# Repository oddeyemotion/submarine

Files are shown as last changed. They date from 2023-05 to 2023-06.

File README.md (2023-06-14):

# Brief introduction

"Submarine" is a hybrid 4WD, Bluetooth-controlled competitive robot car. It is capable of collecting and holding solid game pieces of varying profile while moving across the playing field with desired accuracy and excessively high speed.

Our robot was constructed in a 7-week period regarding M.E.R.C 2023 tournament. In the end we were eliminated from the competition in the quarterfinals, but we gained a lot of new experiences, insights, and connections, and this was honestly an invaluable experience.

Team Submarine: An Thien Dinh (Samuel/Sam), Tan Ngoc Doan, Bao Quang Vo, Huy Quang Nguyen, Hang Thi-Thuy Le (Arris, Team captain).

Official documentation (English): https://oddeyemotion.github.io/odd/projects/p04-submarine

Project logs (Vietnamese): https://projectcocoon.org/projects/209/submarine#tab=logs

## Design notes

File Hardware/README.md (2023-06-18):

# Hardware

In this folder you may find useful resources about our robot's hardware.

## DIY 12-roller omni wheel
STL files for 3D printing can be located in ***DIY 12-roller omni wheel*** folder, or you can also visit [Thingiverse](https://www.thingiverse.com/thing:6040100).

More details about the development of this design at
[Drivetrain - @oddeyemotion's Project Documentation](https://oddeyemotion.github.io/odd/projects/p04-submarine/p04-30-39-technical-details/p04-32-hardware/p04-32-00-drivetrain/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)

This wheel design is part of a robot car project I made with some friends for a school competition, perfectly compatible with common 12mm hex wheel adapter.

I used the original design as a guide to redraw it with the same diameter as my tractor wheels, which are approximately 66-67mm in diameter. I replaced the paper clips, which are about 1mm in diameter, with a bunch of 2mm steel rods that were cut to 25-27mm in length.

Our printer has an error margin of about 0.4mm.

It is recommended to use 3 layers of heat shrink tubing for each roller's coverage.

Order of assembly: Top half 1 - Top half 2 - Middle plus - Middle - Bottom half 2 - Bottom half 1

Secured with:

6x regular 8mm M3 bolts layered with 3x female M3 brass hex standoff pillar rod spacer in the middle
12x regular pairs of 12mm M2 bolts and nuts (recommended 10mm in length for better fit)

## Gripper (final version)
Source files will be updated in the future.

More details about the development of this design at [End effector - @oddeyemotion's Project Documentation](https://oddeyemotion.github.io/odd/projects/p04-submarine/p04-30-39-technical-details/p04-32-hardware/p04-32-02-ee/)

## Gear power transmission system
More details at [Manipulator - @oddeyemotion's Project Documentation](https://oddeyemotion.github.io/odd/projects/p04-submarine/p04-30-39-technical-details/p04-32-hardware/p04-32-01-manipulator/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)

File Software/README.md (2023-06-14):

# Software

In this folder you may find useful resources about our robot's software.

### Chassis-mounted Arduino program
aaaaa

### Gripper-mounted Arduino program
bbbbb

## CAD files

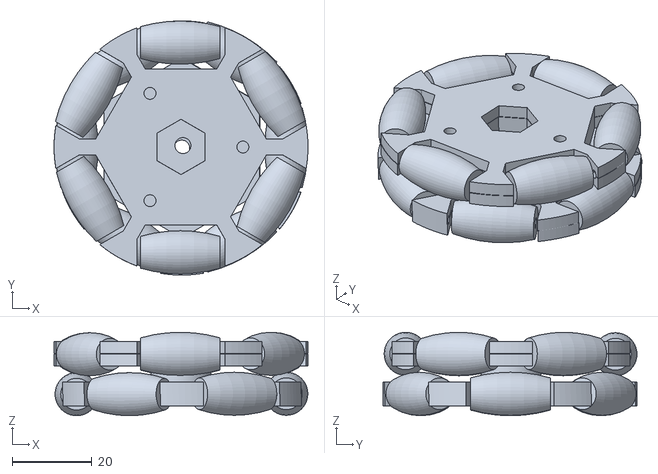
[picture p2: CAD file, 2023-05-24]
3D files/omni wheel 3d.stl
63.6 x 63.6 x 20.9

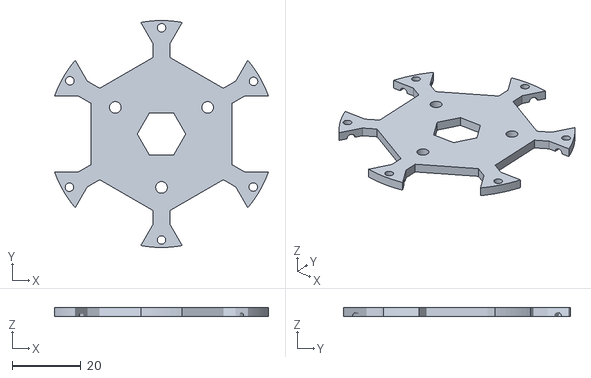
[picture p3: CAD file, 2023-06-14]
Hardware/diy-12-roller-omni-wheel/top half 2 2mm5.stl
62.2 x 66.0 x 2.50

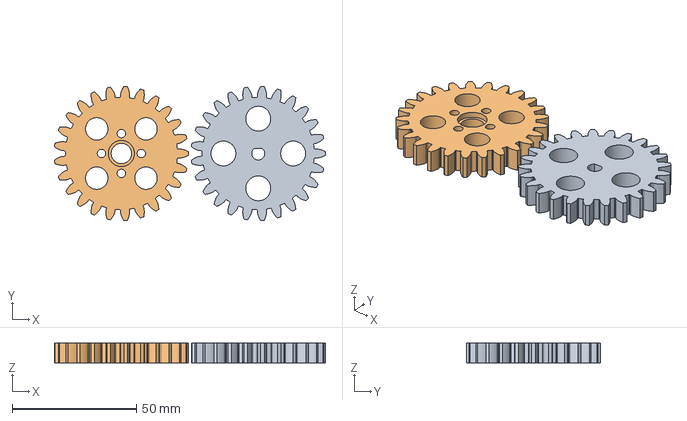
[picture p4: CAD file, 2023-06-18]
Hardware/gear-power-transmission-system/stepper-motor-power-transmission-system.step
108.9 x 54.0 x 8.00 mm
Spur Gear (13 teeth)
Spur Gear (25 teeth)

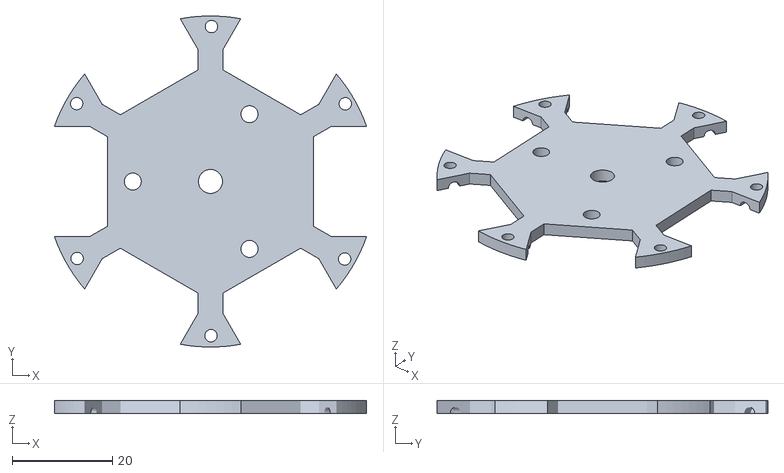
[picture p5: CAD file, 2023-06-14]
Hardware/diy-12-roller-omni-wheel/bottom half 2 2mm5.stl
62.2 x 66.0 x 2.50

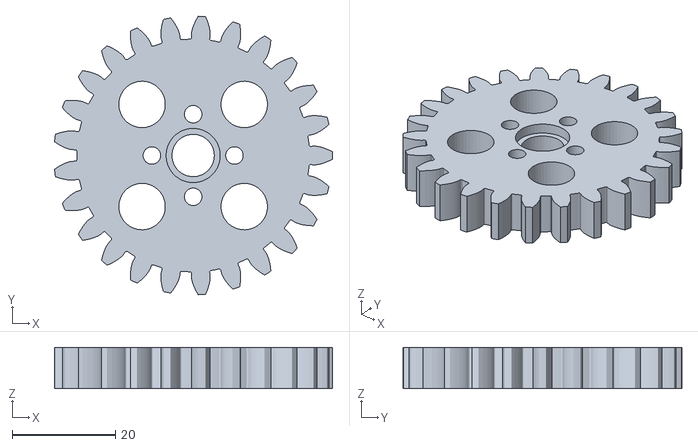
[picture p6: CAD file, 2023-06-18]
Hardware/gear-power-transmission-system/spur-gear-25-teeth-1-1-transmission.stl
53.9 x 54.0 x 8.00

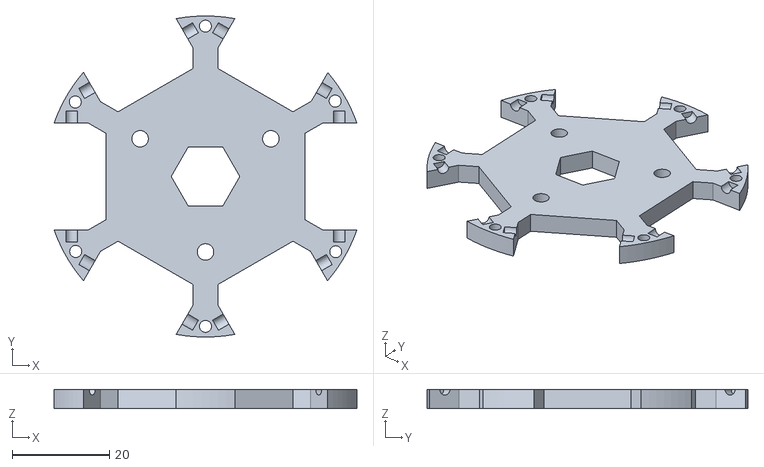
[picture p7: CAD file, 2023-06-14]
Hardware/diy-12-roller-omni-wheel/top half 1 4mm.stl
62.2 x 66.0 x 4.00

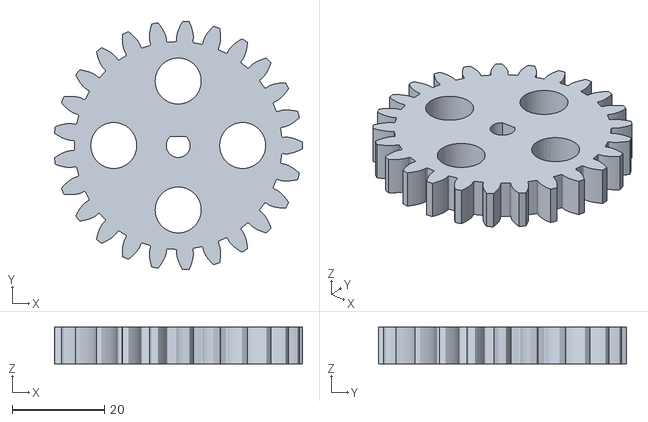
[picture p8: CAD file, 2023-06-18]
Hardware/gear-power-transmission-system/spur-gear-25-teeth-nema-42-stepper.stl
53.9 x 54.0 x 8.00

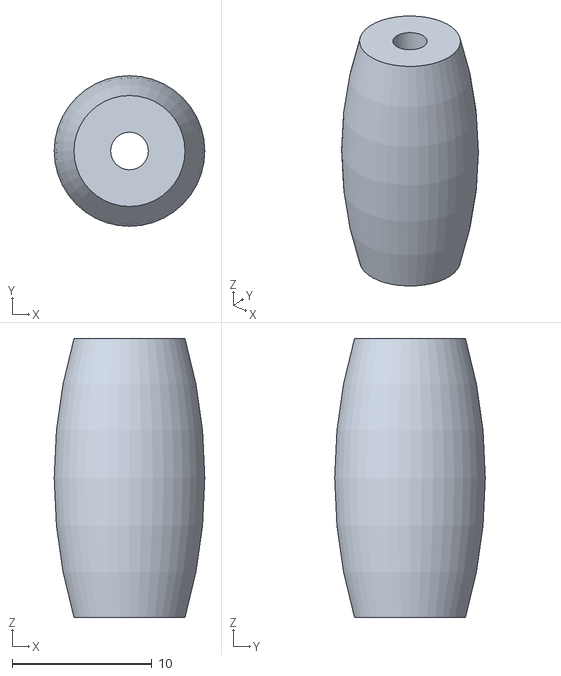
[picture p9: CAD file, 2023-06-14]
Hardware/diy-12-roller-omni-wheel/Omni_Grip_Roller.stl
10.8 x 10.8 x 20.0

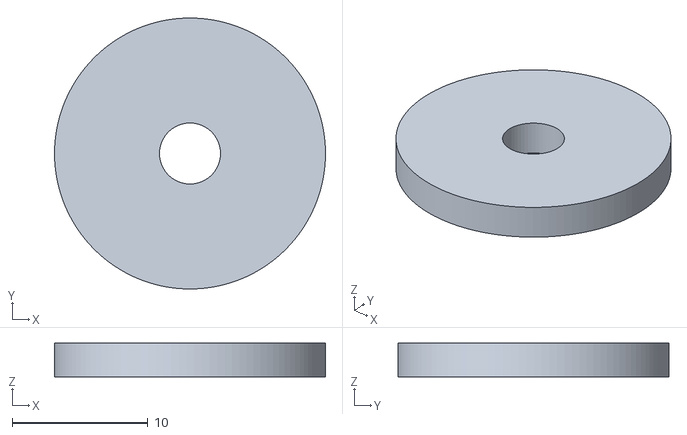
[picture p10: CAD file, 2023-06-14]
Hardware/diy-12-roller-omni-wheel/middle 2mm5.stl
20.0 x 20.0 x 2.50

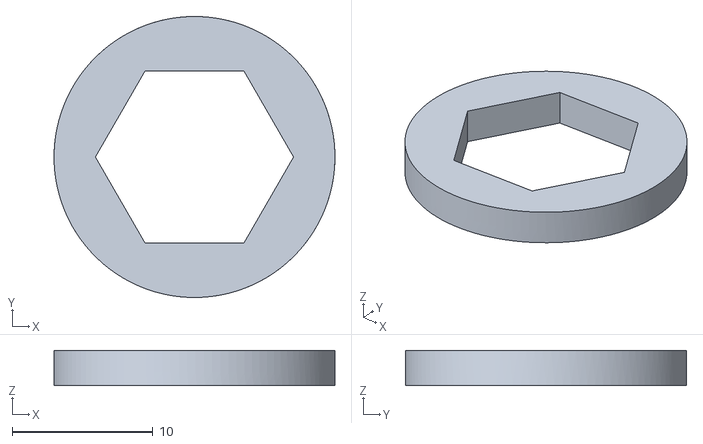
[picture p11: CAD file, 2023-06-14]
Hardware/diy-12-roller-omni-wheel/middle plus 2mm5.stl
20.0 x 20.0 x 2.50

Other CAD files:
Hardware/diy-12-roller-omni-wheel/bottom half 1 4mm.stl
Hardware/gear-power-transmission-system/stepper-motor-power-transmission-system.f3d

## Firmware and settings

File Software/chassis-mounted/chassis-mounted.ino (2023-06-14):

#include <SoftwareSerial.h>
#include <util/atomic.h>
#include <Wire.h>

//Mega
/*
 only the following can be used for RX: 10, 11, 12, 13, 14, 15, 50, 51, 52, 53, A8 (62), A9 (63), A10 (64), A11 (65), A12 (66), A13 (67), A14 (68), A15 (69)
 */
const int MPU = 0x68; // MPU6050 I2C address
float GyroX;
float gyroAngleX; //used in void loop()
float AccErrorX, GyroErrorX;
float elapsedTime, currentTime, previousTime;
int c = 0;
int temp = 0;
int  SpeedTurn = 190;
float previousAngleX = 0;

#define dirPin 6
#define stepPin 7

#define ENLF  2 // LF = Left Front = motor số 2, mạch cầu A
#define ENRF  3 // RF = Right Front = motor số 1, mạch cầu A
#define ENLB  4 // LB = Left Back = motor số 4, mạch cầu B
#define ENRB  5 // RB = Right Back = motor số 3, mạch cầu B
    
#define LF1  22 //IN3A, LF = Left Front = motor số 2, mạch cầu A
#define LF2  23 //IN4A, LF = Left Front = motor số 2, mạch cầu A
#define RF1  24 //IN1A, RF = Right Front = motor số 1, mạch cầu A
#define RF2  25 //IN2A, RF = Right Front = motor số 1, mạch cầu A
    
#define LB1  26 //IN3B, LB = Left Back = motor số 4, mạch cầu B
#define LB2  27 //IN4B, LB = Left Back = motor số 4, mạch cầu B
#define RB1  28 //IN1B, RB = Right Back = motor số 3, mạch cầu B
#define RB2  29 //IN2B, RB = Right Back = motor số 3, mạch cầu B
int command;
int Speed=130;
int LSpeed = Speed;
int RSpeed = Speed;
SoftwareSerial mySerial(50,51); //(TX,RX)

void setup() {
  Serial.begin(9600);
  Wire.begin();                      // Initialize comunication
  Wire.beginTransmission(MPU);       // Start communication with MPU6050 // MPU=0x68
  Wire.write(0x6B);                  // Talk to the register 6B
  Wire.write(0x00);                  // Make reset - place a 0 into the 6B register
  Wire.endTransmission(true);        //end the transmission
  // Call this function if you need to get the IMU error values for your module
  calculateError();
  delay(20);
  pinMode(LF1,OUTPUT);
  pinMode(LF2,OUTPUT);
  pinMode(RF1,OUTPUT);
  pinMode(RF2,OUTPUT);
  
  pinMode(ENLF,OUTPUT);
  pinMode(ENRF,OUTPUT);
  
  pinMode(LB1,OUTPUT);
  pinMode(LB2,OUTPUT);
  pinMode(RB1,OUTPUT);
  pinMode(RB2,OUTPUT);

  pinMode(ENLB,OUTPUT);
  pinMode(ENRB,OUTPUT);

  pinMode(stepPin, OUTPUT);
  pinMode(dirPin, OUTPUT);

  mySerial.begin(9600);
}


void Forward(){
 if(gyroAngleX <= -0.5){
  RSpeed = Speed/2;
}
else if(gyroAngleX >= 0.5){
  LSpeed = Speed/2;
}
else{
  RSpeed = Speed;
  LSpeed = Speed;
}
previousAngleX = gyroAngleX;
calculateGyroAngleX(); 
  digitalWrite(LF1,LOW);
  digitalWrite(LF2,HIGH);
  analogWrite(ENLF,LSpeed);  
  digitalWrite(LB1,LOW);
  digitalWrite(LB2,HIGH);
  analogWrite(ENLB,LSpeed);
  digitalWrite(RF1,LOW);
  digitalWrite(RF2,HIGH);
  analogWrite(ENRF,RSpeed);
  digitalWrite(RB1,LOW);
  digitalWrite(RB2,HIGH);
  analogWrite(ENRB,RSpeed);
  Serial.println(gyroAngleX);
}

void Backward(){

  if(gyroAngleX <= -0.5){
  RSpeed = Speed/1.5;
}
else if(gyroAngleX >= 0.5){
  LSpeed = Speed/1.5;
}
else{
  RSpeed = Speed;
  LSpeed = Speed;
}
calculateGyroAngleX();  
  digitalWrite(LF1,HIGH);
  digitalWrite(LF2,LOW);
  analogWrite(ENLF,LSpeed);  
  digitalWrite(LB1,HIGH);
  digitalWrite(LB2,LOW);
  analogWrite(ENLB,LSpeed);
  digitalWrite(RF1,HIGH);
  digitalWrite(RF2,LOW);
  analogWrite(ENRF,RSpeed);
  digitalWrite(RB1,HIGH);
  digitalWrite(RB2,LOW);
  analogWrite(ENRB,RSpeed);
}
void Right() {
  digitalWrite(LF1,HIGH);
  digitalWrite(LF2,LOW);
  analogWrite(ENLF,SpeedTurn);
  digitalWrite(RF1,LOW);
  digitalWrite(RF2,HIGH);
  analogWrite(ENRF,SpeedTurn);
  digitalWrite(LB1,HIGH);
  digitalWrite(LB2,LOW);
  analogWrite(ENLB,SpeedTurn);
  digitalWrite(RB1,LOW);
  digitalWrite(RB2,HIGH);
  analogWrite(ENRB,SpeedTurn);
}
void Left() {
  digitalWrite(LF1,LOW);
  digitalWrite(LF2,HIGH);
  analogWrite(ENLF,SpeedTurn);
  digitalWrite(RF1,HIGH);
  digitalWrite(RF2,LOW);
  analogWrite(ENRF,SpeedTurn);
  digitalWrite(LB1,LOW);
  digitalWrite(LB2,HIGH);
  analogWrite(ENLB,SpeedTurn);
  digitalWrite(RB1,HIGH);
  digitalWrite(RB2,LOW);
  analogWrite(ENRB,SpeedTurn);
}
void forwardleft() {
  digitalWrite(LF1,LOW);
  digitalWrite(LF2,HIGH);
  analogWrite(ENLF,Speed);  
  digitalWrite(LB1,LOW);
  digitalWrite(LB2,HIGH);
  analogWrite(ENLB,Speed);
  digitalWrite(RF1,LOW);
  digitalWrite(RF2,HIGH);
  analogWrite(ENRF,Speed/3);
  digitalWrite(RB1,LOW);
  digitalWrite(RB2,HIGH);
  analogWrite(ENRB,Speed/3);
}
void forwardright() {
  digitalWrite(LF1,LOW);
  digitalWrite(LF2,HIGH);
  analogWrite(ENLF,Speed/3);
  digitalWrite(RF1,LOW);
  digitalWrite(RF2,HIGH);
  analogWrite(ENRF,Speed);///3
  digitalWrite(LB1,LOW);
  digitalWrite(LB2,HIGH);
  analogWrite(ENLB,Speed/3);
  digitalWrite(RB1,LOW);
  digitalWrite(RB2,HIGH);
  analogWrite(ENRB,Speed);
}
void backleft() {
  digitalWrite(LF1,HIGH);
  digitalWrite(LF2,LOW);
  analogWrite(ENLF,Speed);
  digitalWrite(RF1,HIGH);
  digitalWrite(RF2,LOW);
  analogWrite(ENRF,Speed/3);
  digitalWrite(LB1,HIGH);
  digitalWrite(LB2,LOW);
  analogWrite(ENLB,Speed);
  digitalWrite(RB1,HIGH);
  digitalWrite(RB2,LOW);
  analogWrite(ENRB,Speed/3);
}
void backright() {
  digitalWrite(LF1,HIGH);
  digitalWrite(LF2,LOW);
  analogWrite(ENLF,Speed/3);
  digitalWrite(RF1,HIGH);
  digitalWrite(RF2,LOW);
  analogWrite(ENRF,Speed);
  digitalWrite(LB1,HIGH);
  digitalWrite(LB2,LOW);
  analogWrite(ENLB,Speed/3);
  digitalWrite(RB1,HIGH);
  digitalWrite(RB2,LOW);
  analogWrite(ENRB,Speed);
}
void Stop() {
  digitalWrite(LF1,LOW);
  digitalWrite(LF2,LOW);
  analogWrite(ENLF,0);
  digitalWrite(RF1,LOW);
  digitalWrite(RF2,LOW);
  analogWrite(ENRF,0);
  digitalWrite(LB1,LOW);
  digitalWrite(LB2,LOW);
  analogWrite(ENLB,0);
  digitalWrite(RB1,LOW);
  digitalWrite(RB2,LOW);
  analogWrite(ENRB,0);
}

void loop() {
  char i;
  if (mySerial.available()>0)
  {
  i= mySerial.read();
  Stop();
  LSpeed = Speed;
  RSpeed = Speed;
  Serial.println(gyroAngleX);
  switch (i) {
      case 'F':
        Forward();
        break;
      case 'B':
        Backward();
        break;
      case 'L':
        gyroAngleX = 0;
        Left();
        break;
      case 'R':
        gyroAngleX = 0;
        Right();
        break;
      case 'G':
        gyroAngleX = 0;
        forwardleft();
        break;
      case 'I':
        gyroAngleX = 0;
        forwardright();
        break;
      case 'H':
        gyroAngleX = 0;
        backleft();
        break;
      case 'J':
        gyroAngleX = 0;
        backright();
        break;    
       case 'W':
        digitalWrite(dirPin, HIGH);
        temp = 1;
        break;     
       case 'w':
        temp = 0;
        break;          
      case 'U':
        digitalWrite(dirPin, LOW);
        temp = 1;
        break;
      case 'u':
        temp = 0;
        break;    
      case '0':
        Stop();
        break;
        //set speed
      case '1':
        Speed = 90;
        break;
      case '2':
        Speed = 100;
        break;
      case '3':
        Speed = 120;
        break;
      case '4':
        Speed = 130;
        break;
      case '5':
        Speed = 150;
        break;
      case '6':
        Speed = 170;
        break;
      case '7':
        Speed = 190;
        break;
      case '8':
        Speed = 210;
        break;
      case '9':
        Speed = 230;
        break;
      case 'q':
        Speed = 255;
        break;
    }      

    }
  if(temp == 1){
  digitalWrite(stepPin, LOW);
  delayMicroseconds(2000);
  digitalWrite(stepPin, HIGH);
  delayMicroseconds(2000);  
  }
  else if(temp == 0){
  digitalWrite(stepPin, LOW); 
  digitalWrite(stepPin, LOW);
  }
  }
void calculateGyroAngleX(){
  previousTime = currentTime;
  currentTime = micros();
  elapsedTime = (currentTime - previousTime) / 1000000; 
  readGyro();
  GyroX -= GyroErrorX; 
  gyroAngleX += GyroX*elapsedTime  ; 
  
}

void calculateError() {
  // Read gyro values 200 times
  for(int i=0; i<200; i++) {
    readGyro();
    // Sum all readings
    GyroErrorX += GyroX;
  }
  GyroErrorX = GyroErrorX / 200;
  }
void readGyro() {
  Wire.beginTransmission(MPU);
  Wire.write(0x43);
  Wire.endTransmission(false);
  Wire.requestFrom(MPU, 6, true);
  GyroX = (Wire.read() << 8 | Wire.read()) / 131.0;
}

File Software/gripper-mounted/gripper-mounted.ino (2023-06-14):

#include <Wire.h>
#include <Adafruit_PWMServoDriver.h>
#include <SoftwareSerial.h>
Adafruit_PWMServoDriver pwm = Adafruit_PWMServoDriver();
int command;
#define SERVOMIN  0 // This is the 'minimum' pulse length count (out of 4096)
#define SERVOMAX  500 // This is the 'maximum' pulse length count (out of 4096)
#define USMIN  600 // This is the rounded 'minimum' microsecond length based on the minimum pulse of 150
#define USMAX  2400 // This is the rounded 'maximum' microsecond length based on th
#define maximum pulse of 600
#define SERVO_FREQ 50 // Analog servos run at ~50 Hz updates

#define hand1 0
#define hand2 2
#define wrist 4


int hand1_pulse;
int wrist_pulse;
int hand2_pulse;

SoftwareSerial mySerial(11,12); //(TX,RX)

void setup() {
  Serial.begin(9600);
  pwm.begin();
  
 pwm.setOscillatorFrequency(27000000);
 pwm.setPWMFreq(SERVO_FREQ);  // Analog servos run at ~50 Hz updates
  mySerial.begin(9600);
  delay(10);

  pwm.setPWM(wrist, 0, 70);
}
void loop() {
    char i;
  if (mySerial.available()>0)
  {
  i= mySerial.read();

  Serial.println(wrist_pulse);
   switch (i) {
    case 'F':        
        if(wrist_pulse > 500) wrist_pulse = 500;
        else{
        wrist_pulse = wrist_pulse + 10;
        pwm.setPWM(wrist, 0, wrist_pulse);
        }
        break;
    case 'B':
        if(wrist_pulse < 70) wrist_pulse = 70;
        else{
        wrist_pulse = wrist_pulse - 10;
        pwm.setPWM(wrist, 0, wrist_pulse);
        }
        break;
    case 'W': 
        if(wrist_pulse < 70) wrist_pulse = 70;
        else{
        wrist_pulse = wrist_pulse - 10;
        pwm.setPWM(wrist, 0, wrist_pulse);
        }
        break;
    case 'B':
        if(wrist_pulse < 70) wrist_pulse = 70;
        else{
        wrist_pulse = wrist_pulse - 10;
        pwm.setPWM(wrist, 0, wrist_pulse);
        }
        break;     
   }
  }
}

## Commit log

2023-06-14 Added Hardware and Software folder
    also Omni wheel 3D files
    [Omni_Grip_Roller.stl, bottom half 1 4mm.stl, bottom half 2 2mm5.stl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]
2023-06-18 gear system
    [spur-gear-25-teeth-1-1-transmission.stl, spur-gear-25-teeth-nema-42-stepper.stl, stepper-motor-power-transmission-system.f3d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]
